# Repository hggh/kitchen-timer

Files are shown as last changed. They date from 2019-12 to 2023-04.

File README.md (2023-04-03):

# kitchen-timer

## parts

 * Atmel 328p (1Mhz, BOD disabled)
 * 32 khz crystal (timer2, async)
 * TM1637 – 4 Digit 7 Segment Display
 * Rotary encoder KY-040
 * TP4056 with DW01-P
 * LiPo 18650
 * buzzer
 
## BOM

| Qty |typ|
|---|---|
| 3  | 100nf smd 0805 |
| 2  | 10µF smd 0805 |
| 1  | TP4056 |
| 2 | BC817 |
| 1 | BC807|
| 2 | 10k smd 0805 |
| 3 | 2.6k smd 0805|
| 1 | 0.4 smd 1206
| 1 | 20k smd 0805 |
| 1 | 2k smd 0805 |
| 1 | 100 smd 0805 |
|1 | 1k smd 0805|
| 2 | 4.7k smd 0805 |
| 1 | ATmega 328-PU |
| 1 | FS8025A |
| 1 | DW01A |
| 1 | 32khz crystal |
| 1 | KY-040 |
| 1 | battery holder 18650 |
| 1 | lipo 18650|

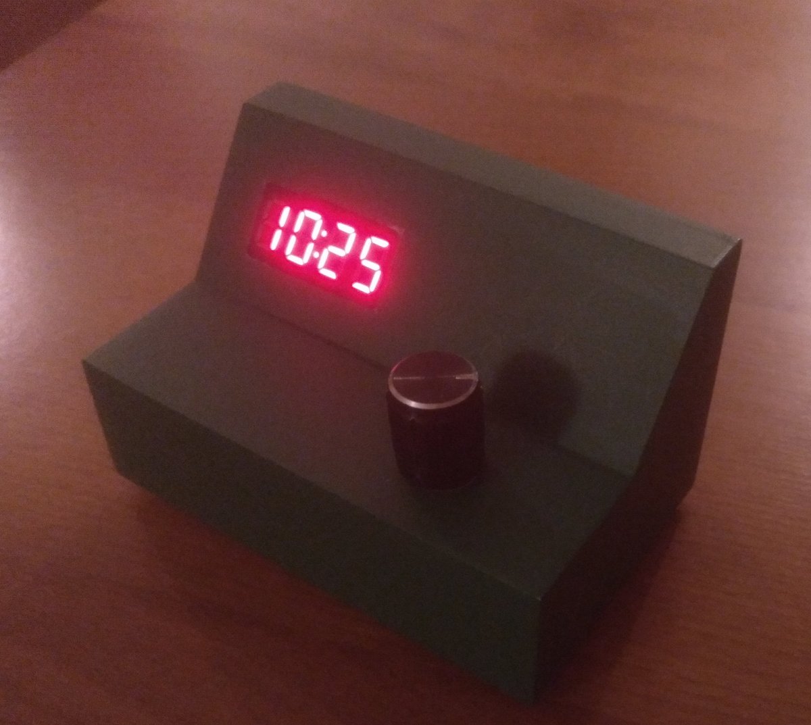
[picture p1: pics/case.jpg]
case

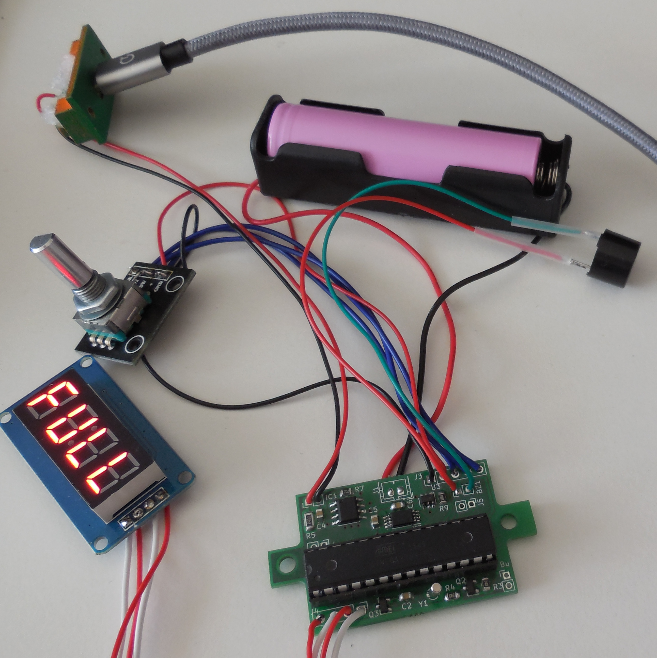
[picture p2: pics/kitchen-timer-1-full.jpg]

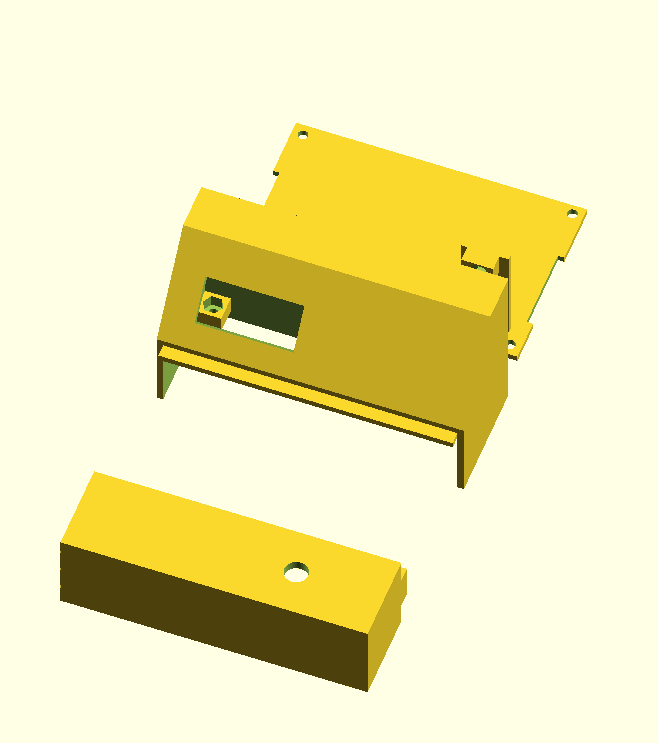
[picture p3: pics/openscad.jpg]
openscad


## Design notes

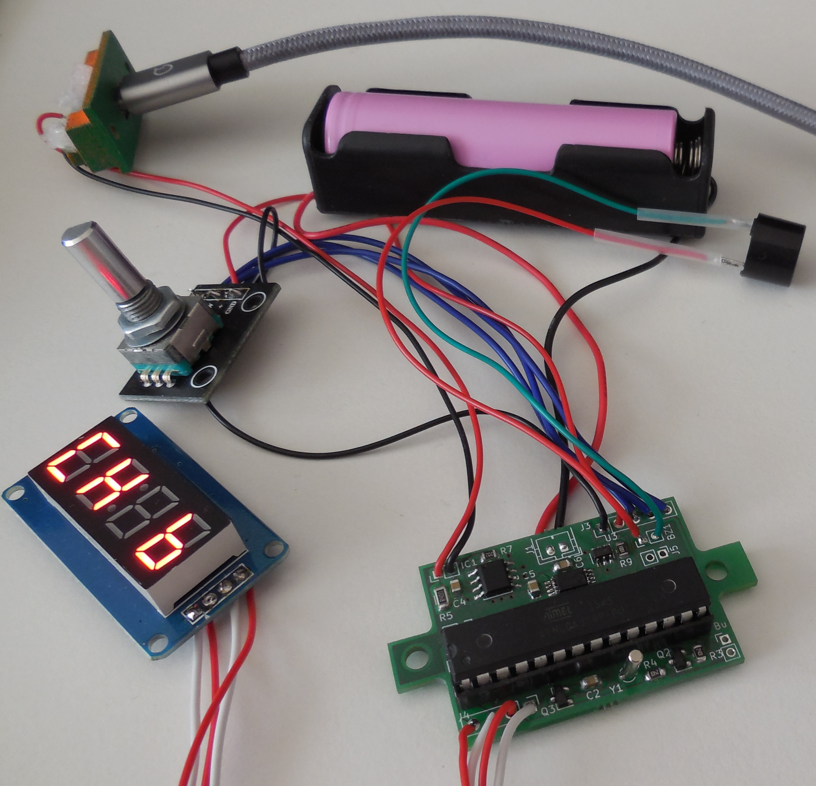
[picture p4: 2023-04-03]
pics/kitchen-timer-1-loading.jpg

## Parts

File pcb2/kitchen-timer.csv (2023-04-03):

Source: | /home/jonas/entwicklung/kitchen-timer/pcb2/kitchen-timer.kicad_sch
Date: | Mo 03 Apr 2023 20:20:41 CEST
Tool: | Eeschema 6.0.11+dfsg-1~bpo11+1
Generator: | /usr/share/kicad/plugins/bom_csv_grouped_by_value_with_fp.py
Component Count: | 35
Ref | Qnty | Value | Cmp name | Footprint | Description | Vendor
10k1, | 1 | R | R | Resistor_SMD:R_0805_2012Metric | Resistor
20k1, | 1 | R | R | Resistor_SMD:R_0805_2012Metric | Resistor
BZ1, | 1 | Buzzer | Buzzer | Connector_PinHeader_2.00mm:PinHeader_1x02_P2.00mm_Vertical | Buzzer, polarized
C2, C3, | 2 | 100nf | C | Capacitor_SMD:C_0805_2012Metric | Unpolarized capacitor
C4, C5, | 2 | 10µF | C | Capacitor_SMD:C_0805_2012Metric | Unpolarized capacitor
C6, | 1 | 100nF | C | Capacitor_SMD:C_0805_2012Metric | Unpolarized capacitor
H1, H2, | 2 | MountingHole | MountingHole | MountingHole:MountingHole_3.2mm_M3 | Mounting Hole without connection
IC1, | 1 | TP4056 | TP4056 | tp4056:TP4056_SOP-8-PP | LiPo charger
J1, | 1 | BATT | Conn_01x02_Male | Connector_JST:JST_PH_B2B-PH-K_1x02_P2.00mm_Vertical | Generic connector, single row, 01x02, script generated (kicad-library-utils/schlib/autogen/connector/)
J2, | 1 | SW2 | Conn_01x02_Female | Connector_PinHeader_2.00mm:PinHeader_1x02_P2.00mm_Vertical | Generic connector, single row, 01x02, script generated (kicad-library-utils/schlib/autogen/connector/)
J3, | 1 | RT | Conn_01x05_Male | Connector_PinHeader_2.54mm:PinHeader_1x05_P2.54mm_Vertical | Generic connector, single row, 01x05, script generated (kicad-library-utils/schlib/autogen/connector/)
J4, | 1 | LCD | Conn_01x04_Male | Connector_PinHeader_2.54mm:PinHeader_1x04_P2.54mm_Vertical | Generic connector, single row, 01x04, script generated (kicad-library-utils/schlib/autogen/connector/)
J5, | 1 | RTC | Conn_01x02_Female | Connector_PinHeader_2.00mm:PinHeader_1x02_P2.00mm_Vertical | Generic connector, single row, 01x02, script generated (kicad-library-utils/schlib/autogen/connector/)
J6, | 1 | USB IN | Conn_01x02_Male | Connector_PinHeader_2.00mm:PinHeader_1x02_P2.00mm_Vertical | Generic connector, single row, 01x02, script generated (kicad-library-utils/schlib/autogen/connector/)
J7, | 1 | Conn_01x02_Male | Conn_01x02_Male | Connector_PinHeader_2.00mm:PinHeader_1x02_P2.00mm_Vertical | Generic connector, single row, 01x02, script generated (kicad-library-utils/schlib/autogen/connector/)
Q1, Q2, | 2 | BC817 | BC817 | Package_TO_SOT_SMD:SOT-23 | 0.8A Ic, 45V Vce, NPN Transistor, SOT-23
Q3, | 1 | BC807 | BC807 | Package_TO_SOT_SMD:SOT-23 | 0.8A Ic, 45V Vce, PNP Transistor, SOT-23
R1, | 1 | 10k | R | Resistor_SMD:R_0805_2012Metric | Resistor
R2, R3, R4, | 3 | 2.6k | R | Resistor_SMD:R_0805_2012Metric | Resistor
R5, | 1 | 0.4 | R | Resistor_SMD:R_1206_3216Metric | Resistor
R7, | 1 | 2k | R | Resistor_SMD:R_0805_2012Metric | Resistor
R8, | 1 | 100 | R | Resistor_SMD:R_0805_2012Metric | Resistor
R9, | 1 | 1k | R | Resistor_SMD:R_0805_2012Metric | Resistor
R10, R11, | 2 | 4,7k | R | Resistor_SMD:R_0805_2012Metric | Resistor
U1, | 1 | ATmega328-PU | ATmega328-PU-MCU_Microchip_ATmega | Package_DIP:DIP-28_W7.62mm
U2, | 1 | FS8205A | FS8205A | Package_SO:TSSOP-8_4.4x3mm_P0.65mm
U3, | 1 | DW01A | DW01A | Package_TO_SOT_SMD:SOT-23-6 | battery protection IC protect lion/lipo battery overcharge, overdischarge
Y1, | 1 | 32khz | Crystal_Small | Crystal:Crystal_DS15_D1.5mm_L5.0mm_Vertical | Two pin crystal, small symbol

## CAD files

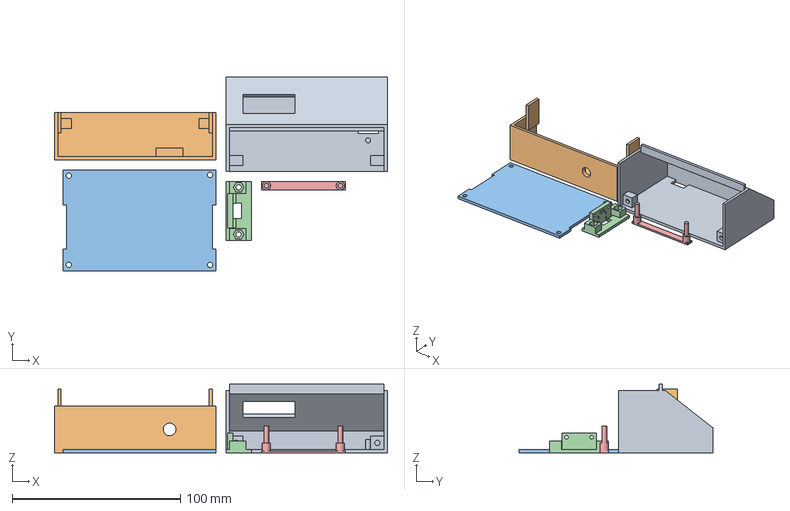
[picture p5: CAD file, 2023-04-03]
case/timer.3mf
198.0 x 115.1 x 41.0 mm
back.stl
front.stl
floor_plate.stl
usbc.stl
pcb_holder.stl

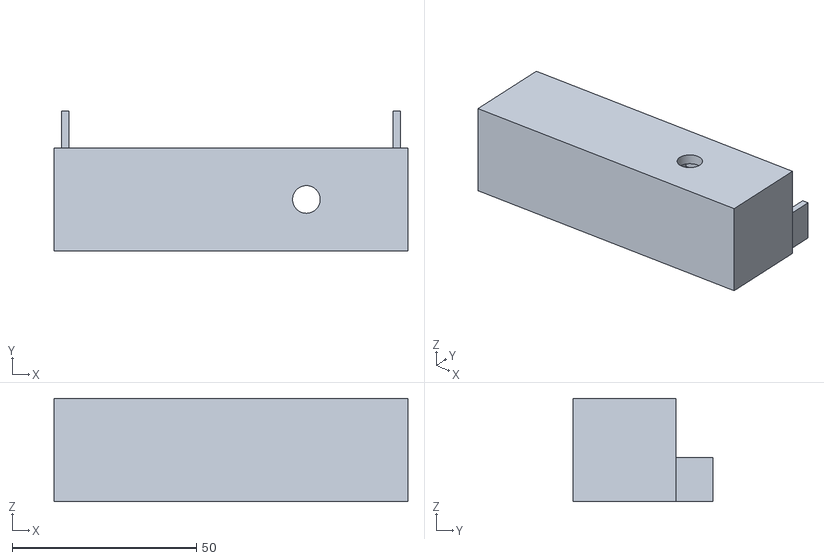
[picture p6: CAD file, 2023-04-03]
case/front.stl
96.0 x 38.0 x 28.0

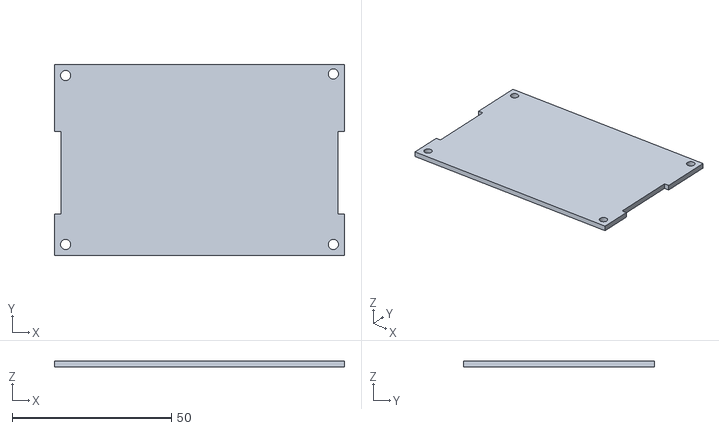
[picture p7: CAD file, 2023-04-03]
case/floor_plate.stl
91.0 x 60.0 x 2.00

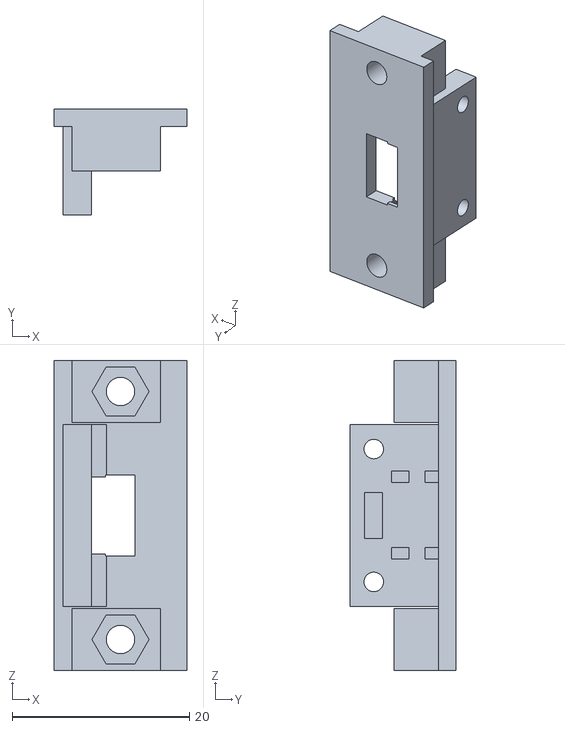
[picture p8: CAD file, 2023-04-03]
case/usbc.stl
15.0 x 12.0 x 35.0

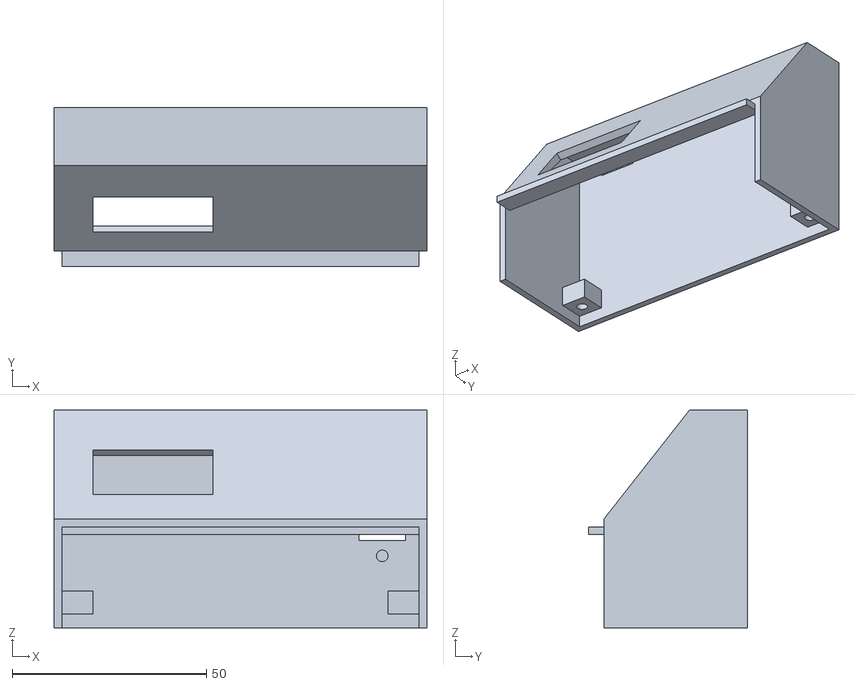
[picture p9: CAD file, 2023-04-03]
case/back.stl
96.0 x 41.0 x 56.0

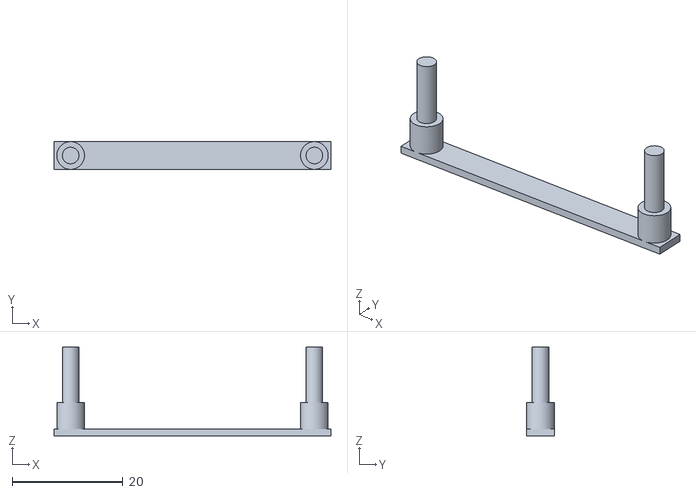
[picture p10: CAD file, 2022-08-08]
case/pcb_holder.stl
50.0 x 5.00 x 16.0

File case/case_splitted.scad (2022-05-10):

use <hggh/mico_usb_breakout_holder.scad>
use <hggh/usb_c_breakout_case_holder.scad>
include <BOSL/constants.scad>
use <BOSL/shapes.scad>


BOX_SIZE_X = 96;
BOX_SIZE_LOWER_Y = 28;
BOX_SIZE_BACK_LOWER_Y = 35;
BOX_SIZE_LOWER_Z = 28;

DISPLAY_POS_X = 10;
DISPLAY_SIZE_X = 30.9;


module mutter_halter() {
    difference() {
        cube([8, 8, 6]);
        translate([8/2, 8/2, 2]) {
            cylinder(r = 5.5 / 2 / cos(180 / 6) + 0.05, h=4.1, $fn=6);
        }
        translate([8/2, 8/2, -0.01]) {
            cylinder(d=3.2, h=3.5, $fn=80);
        }
    }
}

module mutter_halter_front() {
    difference() {
        cube([8, 8, 6]);
        translate([8/2, 8/2, 2]) {
            cylinder(r = 5.5 / 2 / cos(180 / 6) + 0.05, h=4.1, $fn=6);
        }
        translate([8/2, 8/2, -0.01]) {
            cylinder(d=3.2, h=3.5, $fn=80);
        }
    }
}

module front() {
    union() {
        BUTTON_SPACE_X = (BOX_SIZE_X - DISPLAY_SIZE_X - DISPLAY_POS_X) / 2;
        BUTTON_POS_X = DISPLAY_POS_X + DISPLAY_SIZE_X + BUTTON_SPACE_X;
    
        difference() {
            cube([BOX_SIZE_X, BOX_SIZE_LOWER_Y, BOX_SIZE_LOWER_Z]);
            translate([2, 2, -1]) {
                cube([BOX_SIZE_X-4, 28, BOX_SIZE_LOWER_Z-1]);
            }
            translate([BUTTON_POS_X, 28/2, BOX_SIZE_LOWER_Z]) {
                rotate([0, 0, 90]) {
                    cylinder(d=7.5, h=20, center=true, $fn=80);
                }
            }
        }
        difference() {
            translate([BUTTON_POS_X - (16/2), 28/2 - (16/2) , BOX_SIZE_LOWER_Z-3]) {
                cube([16, 16, 1]);
            }
            translate([BUTTON_POS_X, 28/2, BOX_SIZE_LOWER_Z]) {
                rotate([0, 0, 90]) {
                    cylinder(d=7.5, h=20, center=true, $fn=80);
                }
           }
        }
        translate([BUTTON_POS_X - (16/2), 28/2 - (16/2), BOX_SIZE_LOWER_Z-7]) {
            difference() {
                cube([16, 16, 4]);
                translate([1.5, 1.5, -1]) cube([13, 13, 5]);
            }
        }
        translate([2, 2, 3.5]) {
            mutter_halter_front();
        }
        translate([BOX_SIZE_X-2-8, 2, 3.5]) {
            mutter_halter_front();
        }
        // klebeflächen
        translate([2, BOX_SIZE_LOWER_Y-10]) {
            cube([2, 20, 12]);
        }
        translate([BOX_SIZE_X-4, BOX_SIZE_LOWER_Y-10]) {
            cube([2, 20, 12]);
        }
    }
}

TIMER_SIZE_X = 96;
TIMER_BACK_SIZE_Y = 37;
TIMER_BACK_TOP_SIZE_Z = 28;


module floor_plate() {
    size_x = TIMER_SIZE_X - 4;
    size_y = BOX_SIZE_LOWER_Y + TIMER_BACK_SIZE_Y - 4;
    difference() {
        translate([0.5, 0.5, 0]) cube([size_x - 1, size_y - 1, 2]);
        translate([4, 4, -1 ]) cylinder(d=3.2, h=4, $fn=80);
        translate([4, size_y - 4, -1 ]) cylinder(d=3.2, h=4, $fn=80);
        translate([size_x-4, 4, -1 ]) cylinder(d=3.2, h=4, $fn=80);
        translate([size_x-4, size_y - 3.5, -1 ]) cylinder(d=3.2, h=4, $fn=80);

        translate([-0.1, BOX_SIZE_LOWER_Y-10 -4.5, -1]) {
            cube([2.6, 26, 4]);
        }

        translate([size_x-2.5, BOX_SIZE_LOWER_Y-10 -4.5, -1]) {
            cube([2.6, 26, 4]);
        }
    }
}


module timer_back_case() {
    difference() {
            cube([TIMER_SIZE_X, TIMER_BACK_SIZE_Y, TIMER_BACK_TOP_SIZE_Z]);
            translate([2, -2, -1]) {
                cube([BOX_SIZE_X-4, TIMER_BACK_SIZE_Y, TIMER_BACK_TOP_SIZE_Z - 2]);
                translate([0, 4, 0]) {
                    cube([TIMER_SIZE_X - 4, TIMER_BACK_SIZE_Y - 4, TIMER_BACK_TOP_SIZE_Z + 2]);
                }
            }
            translate([2, -2, BOX_SIZE_LOWER_Z]) {
                cube([BOX_SIZE_X-4, BOX_SIZE_BACK_LOWER_Y, 2]);
            }
        }

    translate([2, -4,  TIMER_BACK_TOP_SIZE_Z - 4]) {
        cube([BOX_SIZE_X-4, 6, 2]);
    }
    translate([TIMER_SIZE_X/2, TIMER_BACK_SIZE_Y/2, 28]) {
        union() {
            rotate([0, 0, 90]) {
                difference() {
                    prismoid(
                        size1=[TIMER_BACK_SIZE_Y, TIMER_SIZE_X],
                        size2=[15, TIMER_SIZE_X], h=TIMER_BACK_TOP_SIZE_Z,
                        shift=[11,0]);
         
                    prismoid(
                        size1=[TIMER_BACK_SIZE_Y-4, TIMER_SIZE_X-4],
                        size2=[15-4, TIMER_SIZE_X-4], h=TIMER_BACK_TOP_SIZE_Z -2,
                        shift=[11,0]);

                }
            }
        }
    }

}


module timer_back() {
    difference() {
        timer_back_case();
        // display cutout
        translate([DISPLAY_POS_X, BOX_SIZE_LOWER_Z/2, 28]) {
            rotate([55, 0, 0])
                cube([DISPLAY_SIZE_X, 14.5, 20]);
        }
        // switch cutout
        translate([10, BOX_SIZE_LOWER_Z - 2, 47.8]) {
            cube([11.6, 20, 6.2]);
        }
        // USB-C Connector
        translate([TIMER_SIZE_X - 2 - 15 -2, TIMER_BACK_SIZE_Y - 2, 15]) {
            translate([1.5, -10, 7.5]) {
                cube([12, 30, 20]);
            }
        }
    }       
    translate([2, TIMER_BACK_SIZE_Y - 2 - 8, 3.5]) {
        mutter_halter();
    }
    translate([TIMER_SIZE_X - 2-8, TIMER_BACK_SIZE_Y - 2 - 8, 3.5]) {
        mutter_halter();
    }

    // Print the USB- Connecter extra mount it via screws
    translate([TIMER_SIZE_X - 2 - 15 - 2, TIMER_BACK_SIZE_Y - 2, 15]) {
        translate([15/2, -6, 3.5]) {
            rotate([270, 0, 0]) cylinder(d=3.0, h=6, $fn=190);
        }
        translate([15/2, -6, 35-3.5]) {
            rotate([270, 0, 0]) cylinder(d=3.0, h=6, $fn=190);
        }
        //rotate([180, 270, 0]) usb_c_breakout_case_holder();
    }
}

translate([0, 0, 0]) {
    timer_back();
}

translate([0, -80, 0]) {
    front();
}

translate([2.25, 50, -1]) {
    floor_plate();
}

translate([TIMER_SIZE_X - 2 - 15 - 2, 50, 15]) {
    rotate([180, 270, 0]) usb_c_breakout_case_holder();
}

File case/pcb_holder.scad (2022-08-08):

$fn=190;

translate([-3, -2.5, -1]) {
    cube([44 + 3 + 3, 5, 1.2]);
}
cylinder(d=5, h=5);
cylinder(d=3, h=15);
translate([44, 0, 0]) {
    cylinder(d=5, h=5);
    cylinder(d=3, h=15);
}

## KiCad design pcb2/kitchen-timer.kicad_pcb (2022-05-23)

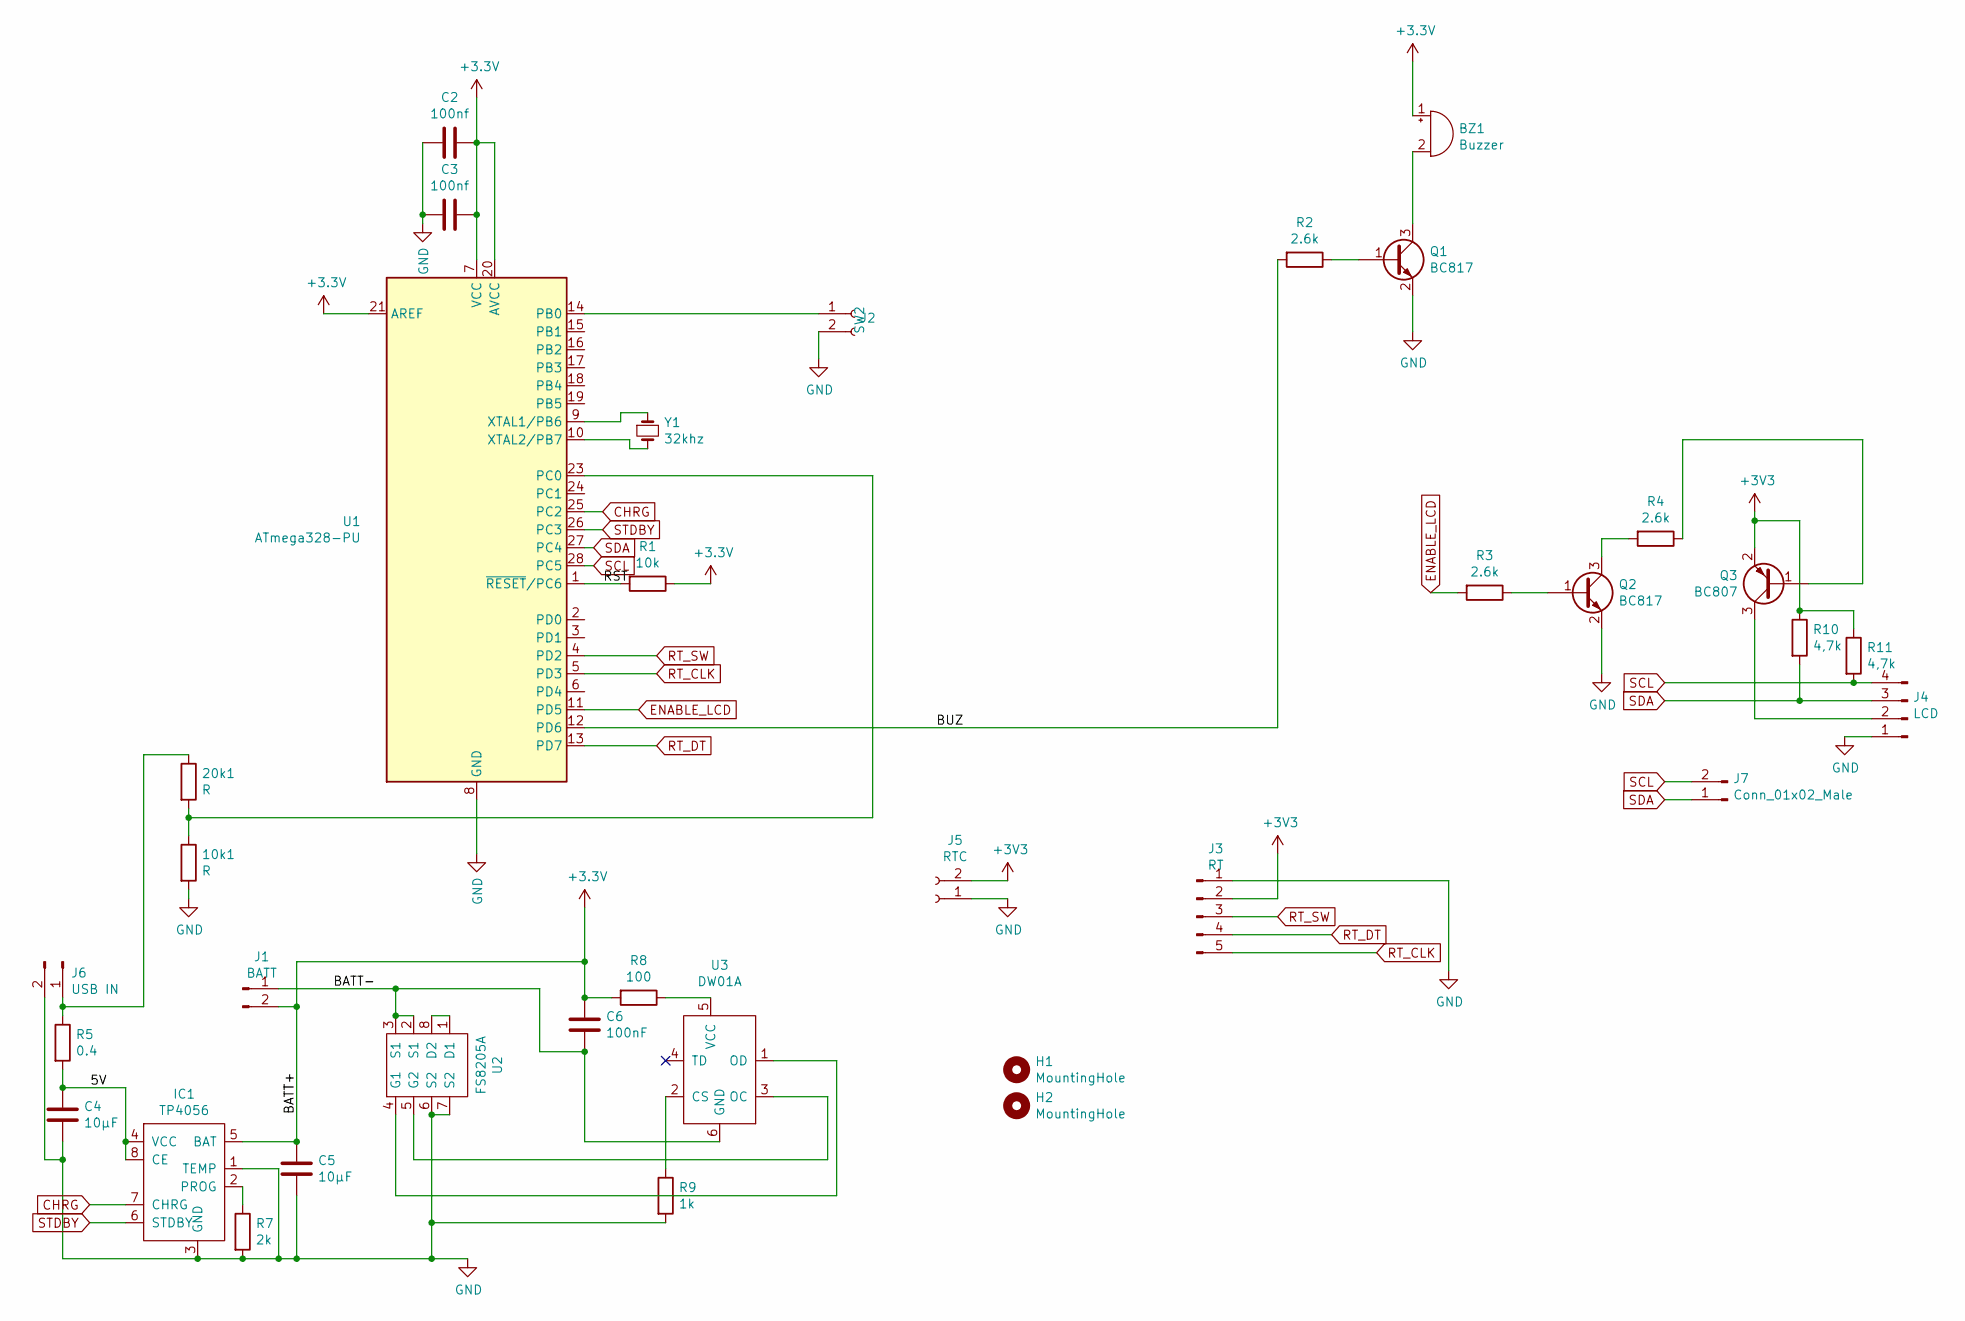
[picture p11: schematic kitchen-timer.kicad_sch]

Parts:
10k1, 20k1: R; R_0805_2012Metric
BZ1: Buzzer; PinHeader_1x02_P2.00mm_Vertical
C2, C3: 100nf; C_0805_2012Metric
C4, C5: 10µF; C_0805_2012Metric
C6: 100nF; C_0805_2012Metric
H1, H2: MountingHole; MountingHole_3.2mm_M3
IC1: TP4056; TP4056_SOP-8-PP
J1: BATT; JST_PH_B2B-PH-K_1x02_P2.00mm_Vertical
J2: SW2; PinHeader_1x02_P2.00mm_Vertical
J3: RT; PinHeader_1x05_P2.54mm_Vertical
J4: LCD; PinHeader_1x04_P2.54mm_Vertical
J5: RTC; PinHeader_1x02_P2.00mm_Vertical
J6: USB IN; PinHeader_1x02_P2.00mm_Vertical
J7: Conn_01x02_Male; PinHeader_1x02_P2.00mm_Vertical
Q1, Q2: BC817; SOT-23
Q3: BC807; SOT-23
R1: 10k; R_0805_2012Metric
R2, R3, R4: 2.6k; R_0805_2012Metric
R5: 0.4; R_1206_3216Metric
R7: 2k; R_0805_2012Metric
R8: 100; R_0805_2012Metric
R9: 1k; R_0805_2012Metric
R10, R11: 4,7k; R_0805_2012Metric
U1: ATmega328-PU; DIP-28_W7.62mm
U2: FS8205A; TSSOP-8_4.4x3mm_P0.65mm
U3: DW01A; SOT-23-6
Y1: 32khz; Crystal_DS15_D1.5mm_L5.0mm_Vertical

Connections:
/5V: C4.1, IC1.4 (VCC), IC1.8 (CE), R5.2
/BATT-: C6.2, J1.1, U2.2 (S1), U2.3 (S1), U3.6 (GND)
/BUZ: R2.2, U1.12 (PD6)
/RST: R1.2, U1.1 (~RESET/PC6)
CHRG: IC1.7 (CHRG), U1.25 (PC2)
ENABLE_LCD: R3.2, U1.11 (PD5)
GND: 10k1.2, C2.2, C3.2, C4.2, C5.2, IC1.1 (TEMP), IC1.3 (GND), J2.2, J3.1, J4.1, J5.1, J6.2, Q1.2 (E), Q2.2 (E), R7.2, R9.2, U1.8 (GND), U1.22 (GND), U2.6 (S2), U2.7 (S2)
unnamed: 10k1.1, 20k1.2, U1.23 (PC0)
unnamed: 20k1.1, J6.1, R5.1
unnamed: BZ1.2 (+), Q1.3 (C)
unnamed: IC1.2 (PROG), R7.1
unnamed: J2.1, U1.14 (PB0)
unnamed: J4.2, Q3.3 (C)
unnamed: Q1.1 (B), R2.1
unnamed: Q2.1 (B), R3.1
unnamed: Q2.3 (C), R4.2
unnamed: Q3.1 (B), R4.1
unnamed: R8.1, U3.5 (VCC)
unnamed: R9.1, U3.2 (CS)
unnamed: U1.9 (XTAL1/PB6), Y1.1
unnamed: U1.10 (XTAL2/PB7), Y1.2
unnamed: U2.1 (D1), U2.8 (D2)
unnamed: U2.4 (G1), U3.1 (OD)
unnamed: U2.5 (G2), U3.3 (OC)
RT_CLK: J3.5, U1.5 (PD3)
RT_DT: J3.4, U1.13 (PD7)
RT_SW: J3.3, U1.4 (PD2)
SCL: J4.4, J7.2, R11.2, U1.28 (PC5)
SDA: J4.3, J7.1, R10.2, U1.27 (PC4)
STDBY: IC1.6 (STDBY), U1.26 (PC3)

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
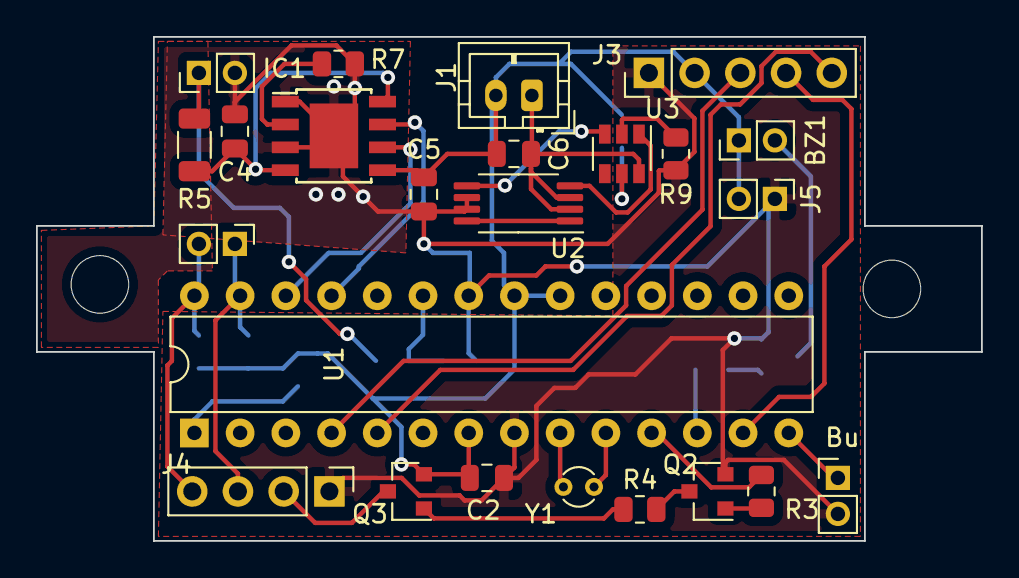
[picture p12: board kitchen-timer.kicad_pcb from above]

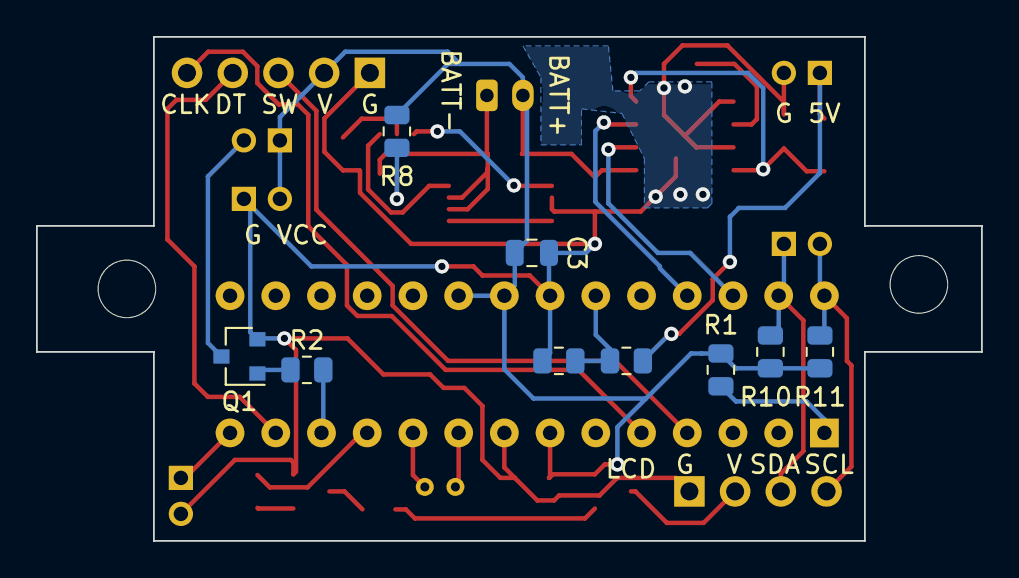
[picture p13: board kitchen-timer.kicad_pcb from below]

Board: 2 copper layers, 52.5 x 28.0 mm, 35 parts (9 on the bottom side), 31 nets.

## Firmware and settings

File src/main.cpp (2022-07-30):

#include <Arduino.h>
#include <EEPROM.h>
#include <avr/power.h>
#include <avr/sleep.h>

#include <TM1637Display.h>
#include <Bounce2.h>

#include <Voltage.h>
#include <TP4056.h>

#include <Menu7Seg.h>

#define BUZZER_PIN 6
#define RT_SW 2
#define RT_CLK 3
#define RT_DT 7
#define DISPLAY_CLK A5
#define DISPLAY_DIO A4
#define ENABLE_LCD 5

#define TP4056_PIN_STDBY A3
#define TP4056_PIN_CHRG A2
//#define TP4056_PIN_USB_PWR A0


#define EEPROM_ADDRESS_ALARM_TIME 0

TM1637Display display(DISPLAY_CLK, DISPLAY_DIO);
Bounce debouncer = Bounce();
Voltage voltage;
Menu7Seg menu = Menu7Seg();
TP4056 tp4056 = TP4056();

const uint8_t LOW_BATT[] = {
  SEG_D | SEG_E | SEG_F,
  SEG_A | SEG_B | SEG_C | SEG_D | SEG_E | SEG_F,
  0x00,
  SEG_A | SEG_B | SEG_C | SEG_D | SEG_E | SEG_F | SEG_G
};

const uint8_t CHARGING_BATT[] = {
  SEG_A | SEG_F | SEG_E | SEG_D,
  SEG_F | SEG_G | SEG_E | SEG_B | SEG_C,
  0x00,
  SEG_C | SEG_D | SEG_E | SEG_F | SEG_G
};

const uint8_t FULL_BATT[] = {
  SEG_A | SEG_F | SEG_G | SEG_E,
  SEG_F | SEG_B | SEG_E | SEG_D | SEG_C,
  SEG_F | SEG_E | SEG_D,
  SEG_F | SEG_E | SEG_D,
};

#define TIMER_MODE_NOTHING 0
#define TIMER_MODE_TIMER_ACTIVE 1
#define TIMER_MODE_FULL_BATT 2
#define TIMER_MODE_MENU_ACTIVE 2

const double battery_low = 2.9;

unsigned long buttonPressTimeStamp;
volatile long wakeup_time = 0;
volatile uint8_t clk_current = 0;
volatile uint8_t clk_last = 0;

short timer_secs_last_start = 300;
volatile short timer_secs_last_pos = 99;
volatile short timer_secs = 300;
volatile short play_sound_status = 0;
volatile short display_enabled = 0;
volatile short timer_mode = TIMER_MODE_NOTHING;
volatile bool update_display = true;
volatile bool wakeup_via_tp4056 = false;

uint8_t setting_alarm_time_seconds = 20;
bool button_long_toggle = false;

int secondsToDisplay(int i) {
  int h = i / 60;

  return (h * 100) + (i - (h * 60));
}


void enable_display() {
  if (display_enabled != 1) {
    digitalWrite(ENABLE_LCD, HIGH);
    display.setBrightness(3);
  }
}

void disable_display() {
  if (display_enabled != 0) {
    digitalWrite(ENABLE_LCD, LOW);
  }
}

void setup_timer() {
  noInterrupts();
  GTCCR |= (1 << TSM) | (1 << PSRASY);
  ASSR |= (1 << AS2);
  TCCR2A = (1 << WGM21);
  TCCR2B |= (1 << CS22) | (1 << CS21);
  OCR2A = 128 - 1; // 1s
  TIMSK2 |= (1<<OCIE2A);
  GTCCR &= ~(1 << TSM);
  interrupts();
}

void goto_sleep() {
  display.clear();
  disable_display();

  set_sleep_mode(SLEEP_MODE_PWR_DOWN);
  sleep_enable();
  sleep_mode();
  sleep_disable();
}

void timer_up() {
  // if timer is running you can not change the value
  if (timer_mode == TIMER_MODE_TIMER_ACTIVE) {
    return;
  }
  if (menu.active()) {
    menu.up();
    return;
  }

  timer_secs_last_pos = timer_secs;
  update_display = true;
  timer_secs += 30;

  if (timer_secs > 5401) {
    timer_secs = 30;
  }
}

void timer_down() {
  // if timer is running you can not change the value
  if (timer_mode == TIMER_MODE_TIMER_ACTIVE) {
    return;
  }
  if (menu.active()) {
    menu.down();
    return;
  }

  timer_secs_last_pos = timer_secs;
  update_display = true;
  timer_secs -= 30;

  if (timer_secs == 0) {
    timer_secs = 5400;
  }
}

void rt_int_sw() {
  if (menu.active()) {
    // if menu is active, just do nothing
    return;
  }
  // just wake up
  enable_display();
  debouncer.update();
  wakeup_time = millis();
  // if alarm is current running, abort it
  if (play_sound_status == 1) {
    play_sound_status = 2;
  }
}

void rt_int_clk() {
  enable_display();
  wakeup_time = millis();
  clk_last = clk_current;
  clk_current = digitalRead(RT_CLK);

  if (clk_last == LOW && clk_current == HIGH) {
    if (digitalRead(RT_DT) == LOW) {
      timer_up();
    }
    else {
      timer_down();
    }
  }
}

ISR(PCINT1_vect) {
  enable_display();
  wakeup_via_tp4056 = true;
  wakeup_time = millis();

  if (tp4056.is_charging() == false && tp4056.is_charged() == false) {
    update_display = true;
  }
}

void disable_timer() {
  noInterrupts();
  GTCCR |= (1 << TSM) | (1 << PSRASY);
  TCCR2A = 0;
  TCCR2B = 0;
  interrupts();
}

ISR(TIMER2_COMPA_vect) {
  TCCR2B = TCCR2B;
  timer_secs_last_pos = timer_secs;
  update_display = true;
  timer_secs--;

  while(ASSR & ((1<<TCN2UB) | (1<<OCR2AUB) | (1<<OCR2BUB) | (1<<TCR2AUB) | (1<<TCR2BUB)));
}


void play(short pin, uint16_t frequency, uint16_t duration) {
  unsigned long start_time = millis();
  unsigned long halfPeriod = 1000000L / frequency / 2;
  pinMode(pin, OUTPUT);
  while (millis() - start_time < duration) {
    digitalWrite(pin, HIGH);
    delayMicroseconds(halfPeriod);

    digitalWrite(pin, LOW);
    delayMicroseconds(halfPeriod);

  }
  pinMode(pin,INPUT);
}


void play_sound() {
  play_sound_status = 1;
  short frequency = 3600;
  for (short i = 0; i < (setting_alarm_time_seconds * 2); i++) {
    play(BUZZER_PIN, frequency, 750);
    if (play_sound_status == 2) {
      // button pressed, abort sound
      break;
    }
    delay(500);
    if (play_sound_status == 2) {
      // button pressed, abort sound
      break;
    }

    if (frequency < 4500) {
      frequency += 200;
    }
  }
  play_sound_status = 0;
}

void setup() {
  // read settings from EEPROM
  EEPROM.get(EEPROM_ADDRESS_ALARM_TIME, setting_alarm_time_seconds);
  if (setting_alarm_time_seconds > 20 || setting_alarm_time_seconds == 0) {
    setting_alarm_time_seconds = 20;
  }
  voltage.init();
  power_usart0_disable();
  power_spi_disable();
  power_twi_disable();

  pinMode(RT_CLK, INPUT_PULLUP);
  pinMode(RT_DT, INPUT_PULLUP);
  pinMode(RT_SW, INPUT_PULLUP);
  pinMode(BUZZER_PIN, INPUT);

  pinMode(ENABLE_LCD, OUTPUT);
  enable_display();

  debouncer.attach(RT_SW);
  debouncer.interval(25);

  attachInterrupt(digitalPinToInterrupt(RT_CLK), rt_int_clk, CHANGE);
  attachInterrupt(digitalPinToInterrupt(RT_SW), rt_int_sw, FALLING);

  wakeup_time = millis();

  menu.init(&debouncer, &display, setting_alarm_time_seconds);

  tp4056.init(TP4056_PIN_CHRG, TP4056_PIN_STDBY);
  tp4056.set_pullup();
  tp4056.setup();

  // interrupts for TP4056
  noInterrupts();
  PCICR |= (1 << PCIE1);
  PCMSK1 |= (1<<PCINT10); // A2
  PCMSK1 |= (1<<PCINT11); // A3
  interrupts();
}
void loop() {
  debouncer.update();
  if (debouncer.fell()) {
    buttonPressTimeStamp = millis();
    button_long_toggle = true;
  }
  if (debouncer.read() == LOW && millis() - buttonPressTimeStamp >= 500 && button_long_toggle == true) {
    // if button is hold too long only do one action
    button_long_toggle = false;
    if (timer_mode == TIMER_MODE_TIMER_ACTIVE) {
      // if timer is active and button is pressed longer, reset timer
      disable_timer();
      timer_mode = TIMER_MODE_NOTHING;
      timer_secs = timer_secs_last_start;
      update_display = true;
    }
    else {
      if (menu.active() == false) {
        // if timer is not active and we have a long press goto menu
        menu.enable();
        timer_mode = TIMER_MODE_MENU_ACTIVE;
      }
      else {
        // if timer is not active and we have a long press and we are inside the menu goto normal mode
        menu.disable();
        timer_mode = TIMER_MODE_NOTHING;
        update_display = true;
        wakeup_time = millis();

        // save settings into eeprom
        setting_alarm_time_seconds = menu.get_alarm_timer_seconds();
        EEPROM.update(EEPROM_ADDRESS_ALARM_TIME, setting_alarm_time_seconds);
      }
    }
    return;
  }
  if (menu.active() == true) {
    menu.update();
    return;
  }
  if (debouncer.rose() && timer_mode == TIMER_MODE_NOTHING && debouncer.previousDuration() < 400) {
    // check battery level before going to timer
    if (battery_low > (double)voltage.read()) {
      display.setSegments(LOW_BATT);
      play(BUZZER_PIN, 2000, 50);
      delay(500);
      play(BUZZER_PIN, 2000, 50);
      delay(500);
    }
    // if button is pressed and timer is not active, start countdown
    play(BUZZER_PIN, 3000, 100);
    timer_secs_last_start = timer_secs;
    timer_mode = TIMER_MODE_TIMER_ACTIVE;
    setup_timer();
  }
  if (timer_mode == TIMER_MODE_TIMER_ACTIVE) {
    if (timer_secs == 0) {
      disable_timer();
      display.showNumberDecEx(0, 64, true);
      timer_mode = TIMER_MODE_NOTHING;
      timer_secs = timer_secs_last_start;
      play_sound();

      // timer is finished, we update display with the last timer pos
      // also set wakeup_via_tp4056 to update display if usb cable is connected
      wakeup_time = millis();
      update_display = true;
      wakeup_via_tp4056 = true;
    }
  }

  if (update_display == true) {
    update_display = false;
    display.showNumberDecEx(secondsToDisplay(timer_secs), 64, false);
  }

  // if usb cable is connected and timer is not running we display chg or full message
  if (wakeup_via_tp4056 == true) {
    wakeup_via_tp4056 = false;
    if (timer_mode == TIMER_MODE_NOTHING) {
      if (tp4056.is_charged() == true) {
        display.setSegments(FULL_BATT);
      }
      if (tp4056.is_charging() == true) {
        display.setSegments(CHARGING_BATT);
      }
    }
  }

  if (tp4056.is_charging() == false && tp4056.is_charged() == false && timer_mode == TIMER_MODE_NOTHING && millis() - wakeup_time >= (10 * 1000)) {
    // if timer is not active and no user action within 10s and not charging and not fully charged => goto sleep
    goto_sleep();
  }
  if (timer_mode == TIMER_MODE_NOTHING && millis() - wakeup_time >= (5 * 1000) && tp4056.is_charged() == true) {
    // if nothing is active and buttons / encoder is not used and battery is full, display message
    display.setSegments(FULL_BATT);
  }
  if (timer_mode == TIMER_MODE_NOTHING && millis() - wakeup_time >= (5 * 1000) && tp4056.is_charging() == true) {
    // if nothing is active and buttons / encoder is not used and battery is full, display message
    display.setSegments(CHARGING_BATT);
  }
}

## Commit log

2019-10-27 add pcb
    [kitchen-timer.kicad_pcb, kitchen-timer.sch]
2019-10-28 added gnd plane on back
    [kitchen-timer.kicad_pcb]
2019-10-30 added case
    [case.scad, case.stl]
2019-10-30 added wood case test
    [wood.scad, wood.stl]
2019-11-05 more designs
    [case.scad, wood.scad]
2019-11-05 new case
    [case.scad, case.stl]
2019-11-05 case update
    [case.scad, case.stl]
2019-11-10 micro usb breakout
    [mico_usb_breakout.scad, mico_usb_breakout.stl]
2019-11-10 update case
    [case.scad, mico_usb_breakout.scad]
2019-11-13 updated case
    [case.scad, case.stl]
2019-11-13 update case with usb connector
    [case.scad, case.stl]
2019-11-16 play sound via delay; tone uses timer2
2019-11-16 add splitted case for better printing
    [case_splitted.scad]
2019-11-17 cleanup cases; add 1.0
    [case.scad, case.stl, case_splitted.stl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]
2019-11-17 old version
    [case.scad, case.stl]
2019-11-22 remember last start pos; update rotery encoder code
2019-11-29 add base plate
    [case_splitted.scad]
2019-12-03 display: size
    [case_splitted.scad]
2020-01-14 add beep if timer stars; longer press
2020-04-23 check battery level before activating timer and warn if too low
    [main.cpp]
2020-05-20 changed to openscad library
    https://github.com/hggh/openscad-utils
    [case_splitted.scad, mico_usb_breakout.scad, mico_usb_breakout.stl]
2021-04-30 enable menu with settings: set time how long the timer will beep
2022-04-23 update case with prismoid function
    [case_splitted.scad]
2022-05-01 add splitted parts new case with USB-C
    [back.stl, case_splitted.scad, case_splitted.stl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]
2022-05-10 update floor plate for new site
    [case_splitted.scad, floor_plate.stl]
2022-05-23 new pcb with tp4056 on the same pcb
    [kitchen-timer.kicad_pcb, kitchen-timer.sch]
2022-07-30 update tp4056 charge load
    [kitchen-timer.sch]
2022-08-08 update stls
    [back.stl, floor_plate.stl, front.stl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]
2023-04-03 add Prusa
    [timer.3mf]
2023-04-03 removed old pcb
    [kitchen-timer.kicad_pcb, kitchen-timer.sch]
2023-04-03 Kicad 6
    [kitchen-timer.csv, kitchen-timer.kicad_sch]
